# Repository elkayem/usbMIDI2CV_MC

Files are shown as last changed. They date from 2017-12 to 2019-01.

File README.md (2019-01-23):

# usbMIDI2CV_MC

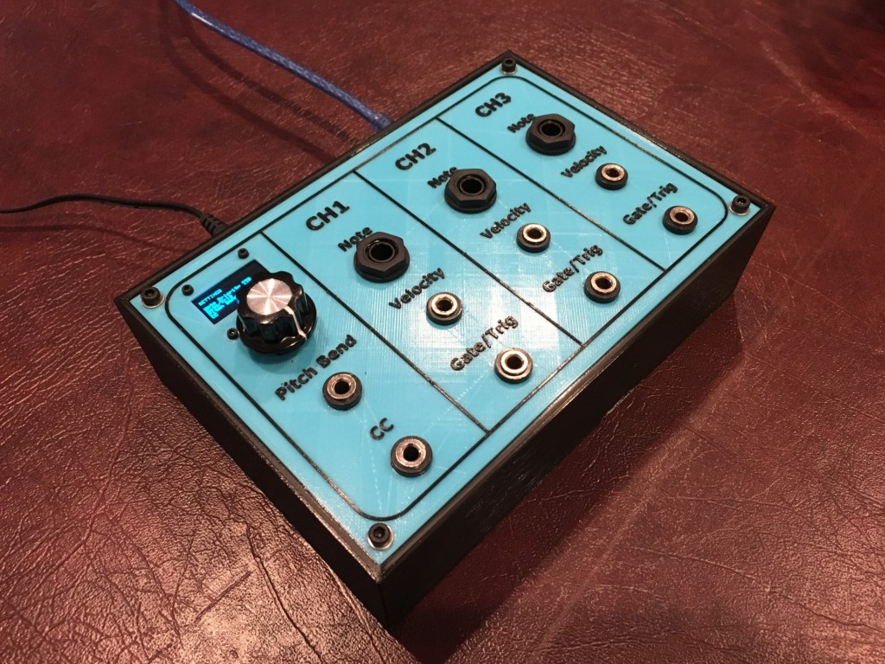
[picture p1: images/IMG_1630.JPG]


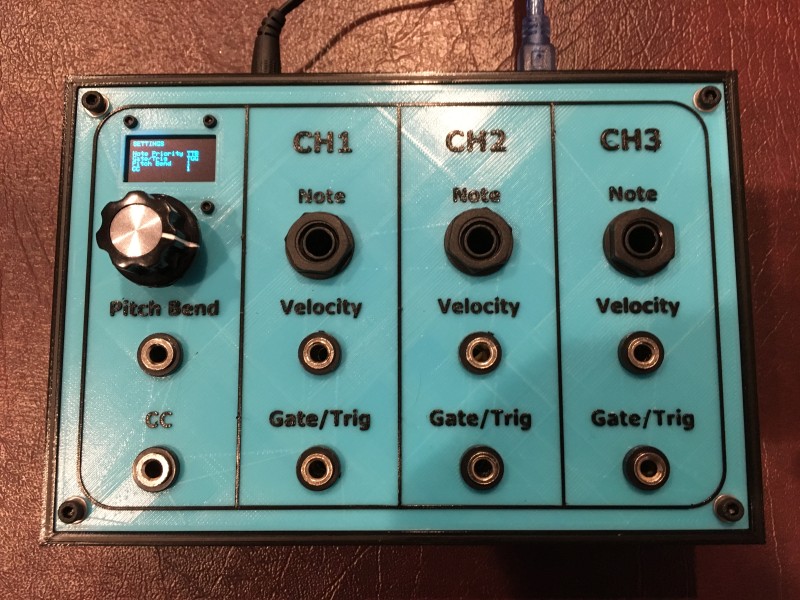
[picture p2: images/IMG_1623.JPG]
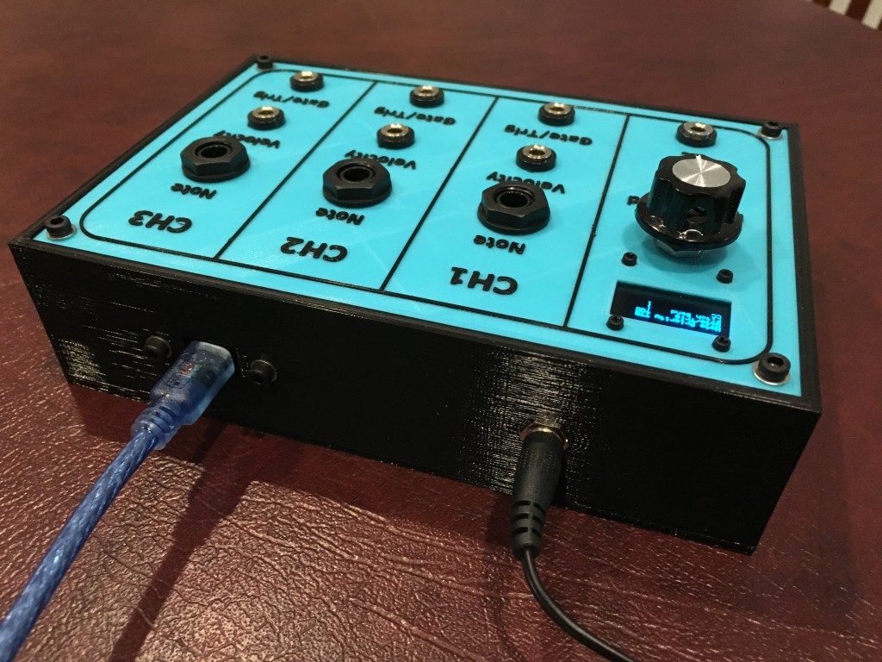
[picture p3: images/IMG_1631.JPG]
 

This repository contains the code and schematics for a three-channel USB-MIDI to CV converter.  STL files are also included for a 3D printed case.  This project has the following features:
* Three channel Note CV output (88 keys, 1V/octave, MIDI channels 1-3) using a 12-bit DAC
* Configurable note priority for each channel (Top Note, Bottom Note, or Last Note Priority)
* Note scale factor calibration configurable in software
* 5V Gate/Trigger outputs, where each channel can be independently configured to either output a gate (output high for entire length of time that note is on) or trigger (20 msec pulse each time a new note is initiated)
* Velocity CV output (0 to 4V) for each channel
* Pitch Bend CV output (0.5 +/- 0.5V), which can be configured for channel 1, 2, or 3
* Control Change CV output (0 to 4V), which can be configured for channel 1, 2, or 3
* OLED user interface, used for setting parameters and saving to EEPROM

This module is the perfect interface between your computer or iPad and an analog synthesizer.  It can independently drive up to three oscillators with 1V/octave CV inputs.  (Connection to an iPad requires the USB camera adapter but is well worth it given the wide variety of great MIDI sequencer apps.)  

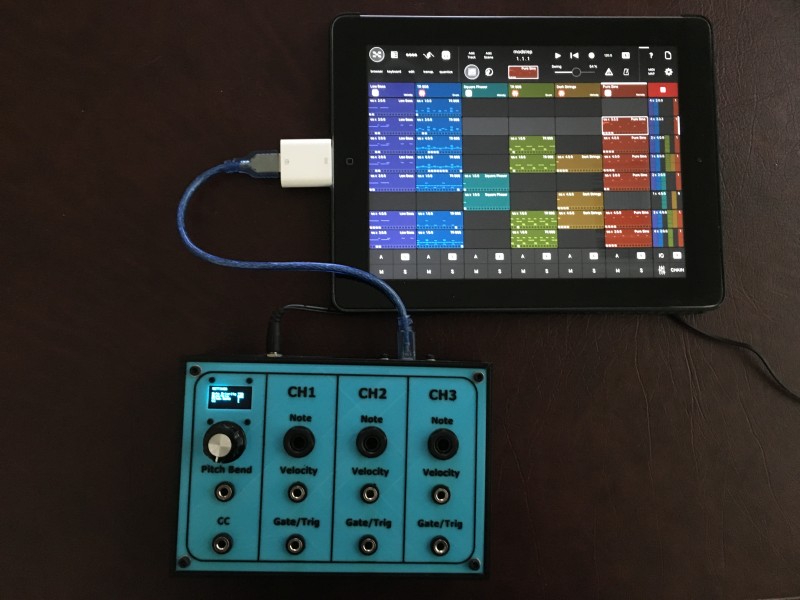
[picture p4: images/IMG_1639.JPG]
 

Note priority can be independengly set for each channel, with the following options:
* **Top Note (aka Highest Note):** When multiple notes are sounded simultaneously, the highest note being held will be sounded.  When the highest note is released, the next highest note will be played, and so on.
* **Bottom Note (aka Lowest Note):** Analagous to top note, except the lowest note being held will be sounded.  
* **Last Note:** The most recent note played will be sounded.  When that note is released, the next most recent note still being held will be sounded.  

The settings screen shows the current settings used.  Note priority is listed as sequence of three letters showing the setting for each of the three channels, where T = Top Note, B = Bottom Note, and L = Last Note.  Similarly, Gate/Trigger is listed as a sequence of three letters where G = Gate and T = Trigger.  Pitch Bend and CC settings show which MIDI channel will be used for the analog output.  Note scale factor can also be calibrated by +/-10%.  All of these settings can be set through the OLED interface using the encoder knob.

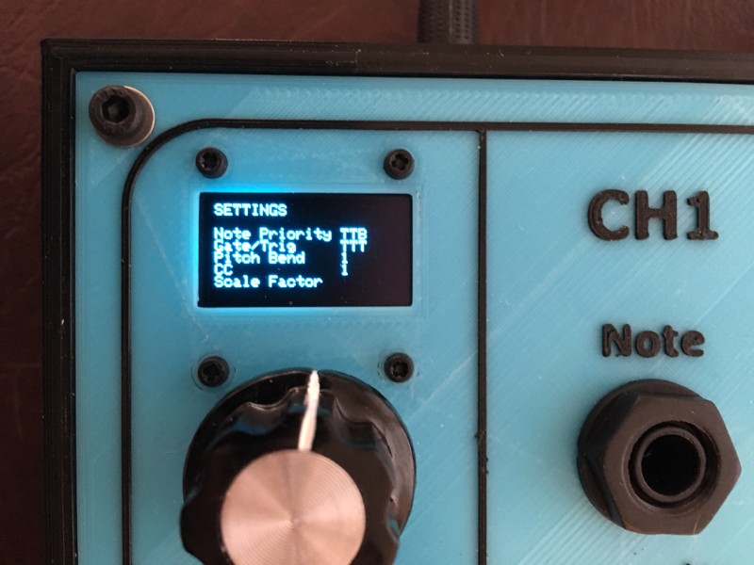
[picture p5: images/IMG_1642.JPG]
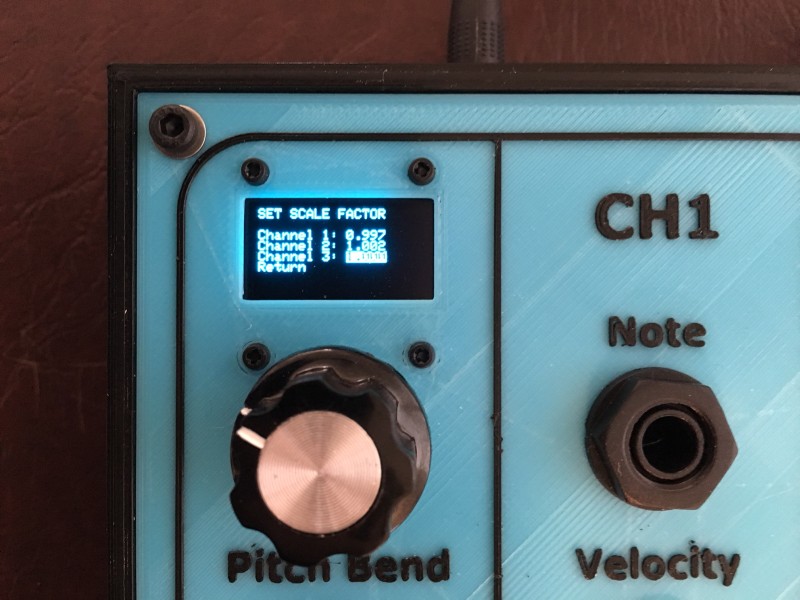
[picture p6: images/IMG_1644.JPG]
 

## Parts List
* Teensy 2.0
* LM7805 5V Voltage Regulator
* 128x64 OLED graphic display, with I2C interface 
* Pushbutton Rotary encoder with knob (should have 5 pins)
* 4x MCP4822 12-bit DACs (8 pin DIP)
* 2x LM324N Quad Op Amp (14 pin DIP)
* 7x 0.1 uF ceramic capacitors
* 0.33 uF capacitor
* 3x 3K resistors (1% metal film)
* 3x 4.7K resistors (1% metal film)
* 3x 10K resistors (1% metal film)
* 3x 2K resistors
* 4x 8 pin DIP IC sockets
* 2x 14 pin DIP IC sockets
* 2x 12-pin female headers
* 8x banana jacks
* 3x 1/4" mono phone jacks
* (Optional) 2-pin 5.08mm pitch screw terminal, for power input 
* Barrel power jack (e.g., 2.1 x 5.5 mm)
* 9 - 12V DC power supply with barrel connector (e.g., 2.1 x 5.5 mm)
* PCB (Gerber files included) or strip board
* 6x 10mm M3 bolts and nuts (4 for panel, 2 for USB port)
* 4x M2 bolts and nuts for mounting the OLED screen
* Panel mount USB 2.0 USB Mini B Female to USB Mini B Male, 1 ft cable (see picture below)

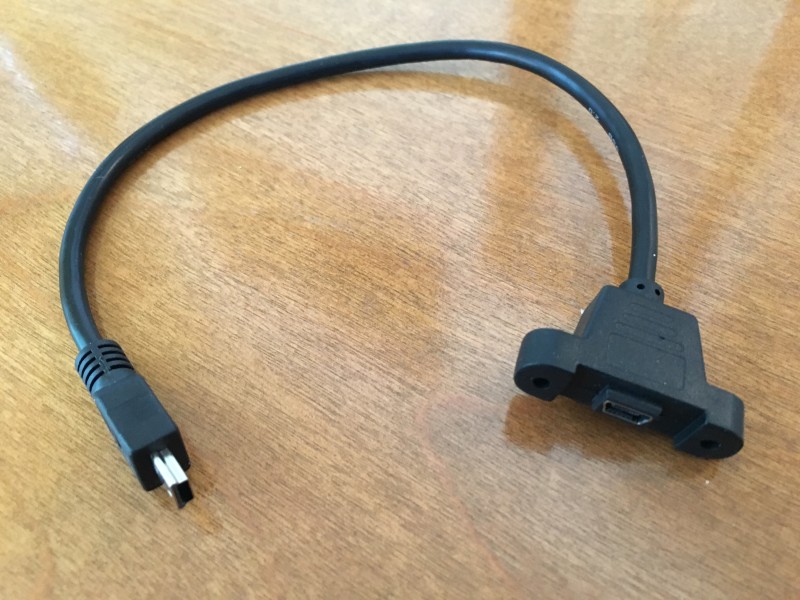
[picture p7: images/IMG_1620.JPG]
 

## Instructions
Electronic components can be soldered to a strip board or (more conveniently) to the PCB design I have included in this repository.  I recommend using IC sockets to mount the ICs and female headers to mount the Teensy.  The PCB can be manufactured by a PCB supplier.  The least expensive way to do this is to upload the gerber files (included as a .zip file) to one of several Chinese manufacturers such as SchenZhen2U, EasyEDA, or Seeed Studio.  pcbshopper.com allows a comparison between vendors.  Typical prices are $1-$3/board, with a minimum of 5 boards.  Recommended default settings are Layers: 2; PCB Thickness: 1.6mm; Surface Finish: HASL; Copper Weight: 1.  (Alternatively, contact me since I may still have a few extras I could send out for $5 + shipping.)

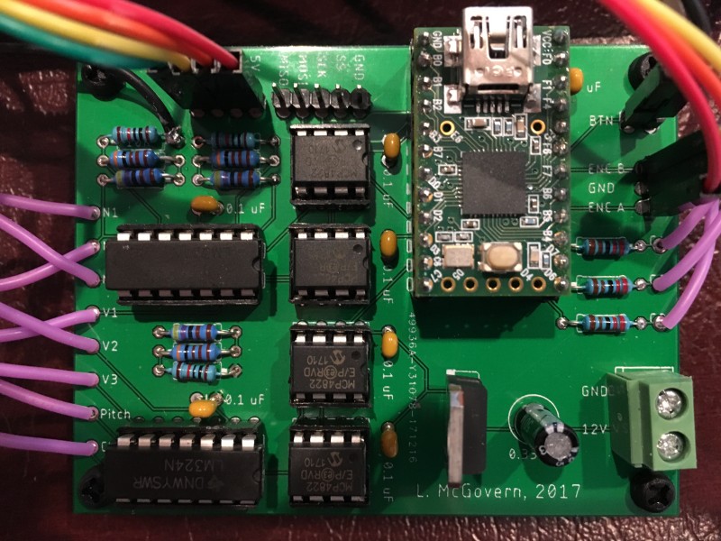
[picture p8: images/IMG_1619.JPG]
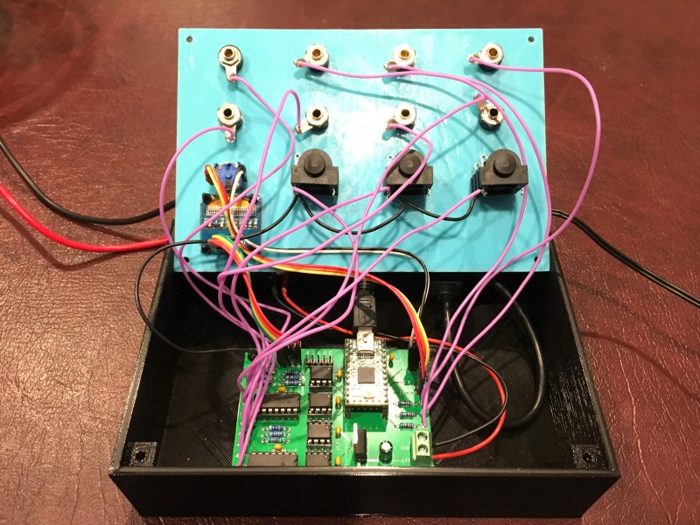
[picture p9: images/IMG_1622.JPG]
 

**Important!** Before connecting the Teensy 2.0 to an external power supply, the 5V pads must be cut on the bottom side of the board.  See https://www.pjrc.com/teensy/external_power.html for details.

The 3D printer STL files are located in the 3D Printer Files folder. I've also included the Sketchup file, in case modifications are needed.  (Download Sketchup Make, it's free!) The panel includes raised text, and so must be printed with two colors. Most slicers include a "pause at height" plugin, which will move the hot end out of the way and allow you to switch filaments. The panels are 3mm thick, and the letters are 0.45mm thick. I printed with 0.15mm layer thickness, allowing the letters to be printed in three layers. Add the command to pause after you finish printing the 3mm layer, so you can change the filament color. (One tip: If you find that your printer is disabling the stepper motors after pausing, you may need to insert M84 S0 at the start of the G-Code. I did.)  

The 3D printed panel must be printed with supports for the OLED screen mount. There is a recessed area on the back side of the panel that fits the screen mounting shape. I recommend picking up the screen by DIYMall, as the hole pattern was designed for that screen. Others may fit as well. Supports are not required for the case.

I have included 1/4" jacks for the CV note outputs to ensure that the analog synthesizer shares a common ground with the MIDI2CV component.  Ground is carried over the sleeve.  The sleeve pins on the phone jacks need to be tied together, and then tied to a ground location on the PCB.  I did not provide a dedicated ground location on the PCB for this connection, but any location on the PCB will work.  (e.g., directly to the power ground input).  I left the remainder of the outputs as banana jacks assuming at least one of the notes is connected.  If desired, the banana jacks can be replaced with phone jacks.  Be aware that the holes in the 3D printed case may need to be enlarged, and and the case may need to be made taller to accomodate the depth of the additional phone jacks. 

The rotary encoder should have three pins on one side and two on the other.  Connect the three pins to the 3 ENC headers on the board, and the two pins to the 2 BTN pins on the board.  These may be connected using jumper wires and male header pins, or soldered directly to the board.

The OLED attaches to the I2C output on the PCB (marked as 5V, GND, SCL, SDA).  Note the pin order!  This order matches a commonly available OLED from DIYMall, but other OLEDs exist with the power and ground swapped.  Swapping power and ground will destroy the OLED.

The firmware can be uploaded to the Teensy 2.0 using the Teensy loader.  See https://www.pjrc.com/teensy/first_use.html for details.  The hex file is included in this repository.  If modification of the source code is required, then the Arduino software and Teensyduino must also be installed (see https://www.pjrc.com/teensy/td_download.html).  Several libraries are used, which are included as part of the Teensyduino installer.  Be sure to configure the board as Teensy 2.0 (under Tools > Board), and USB Port as MIDI (under Tools > USB Type).

**Important Notes if recompiling firmware:**  
* You must be using Teensyduino 1.45 or later to recompile the software.  Earlier versions used a different internal numbering convention for MIDI message types.  The latest version can be downloaded from https://www.pjrc.com/teensy/td_download.html.  
* If the software isn't compiling, check your library version numbers.  I am currently using Adafruit SSD1306 v1.2.9 and Bounce2 v2.52.2.  The remaining libraries should come preinstalled with the Arduino and Teensyduino installers.

If using 1% metal film resistors, the MIDI2CV is likely to be in tune for the entire 7.25 octave (88 key) range.  The DAC output range is 4.096 V, which is amplified by 7.25/4.096 = 1.7700.  This is accomplished with the combination of 3K, 4.7K, and 10K resistors in the op-amp circuit.  (Note 3.01K is also common, and can be used.)  

If the MIDI2CV output scale factor isn't exactly 1V/octave, the scale factor can be adjusted by +/-10% using the user interface.  Mine was fairly close for all three channels, and required adjustment of only a few tenths of a percent.

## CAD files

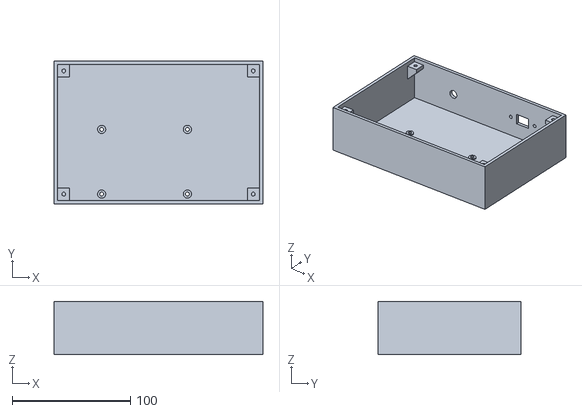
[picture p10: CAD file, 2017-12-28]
3D Printer Files/usbMIDI2CV_MC_case.stl
176.5 x 120.5 x 45.0

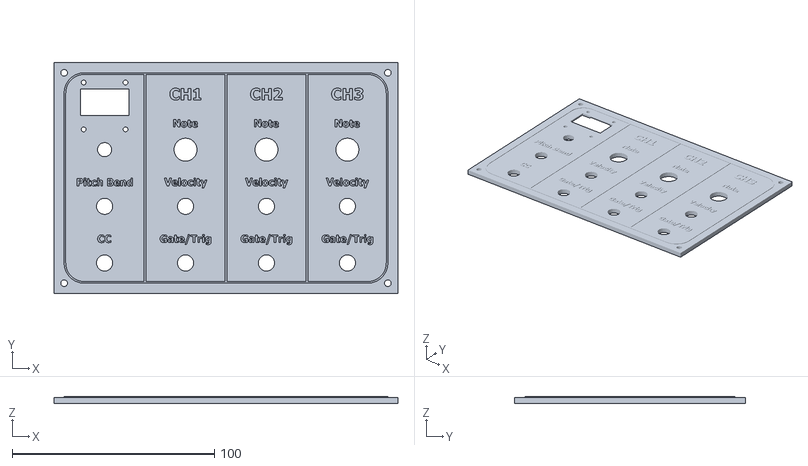
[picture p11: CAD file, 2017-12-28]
3D Printer Files/usbMIDI2CV_MC_panel.stl
170.0 x 114.0 x 3.45

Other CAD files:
3D Printer Files/usbMIDI2CV_MC.skp

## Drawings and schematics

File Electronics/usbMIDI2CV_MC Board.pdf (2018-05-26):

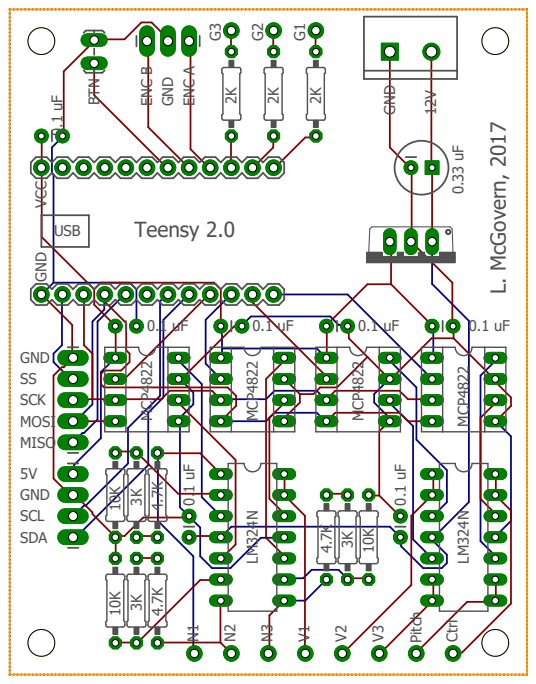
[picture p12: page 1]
MOSI MISO; SCK; GND; 5V GND SCL; SDA; L. McGovern, 2017

ENC B GND ENC A N1N2N3V1V2V3Ctrl G3G2G1 BTN GND 12V GND VCC USB Teensy 2.0 Pitch 2K2K2K 0.33 uF 10K 10K 10K 3K 3K 3K 4.7K 4.7K 4.7K LM324N LM324N MCP4822 MCP4822 MCP4822 MCP4822

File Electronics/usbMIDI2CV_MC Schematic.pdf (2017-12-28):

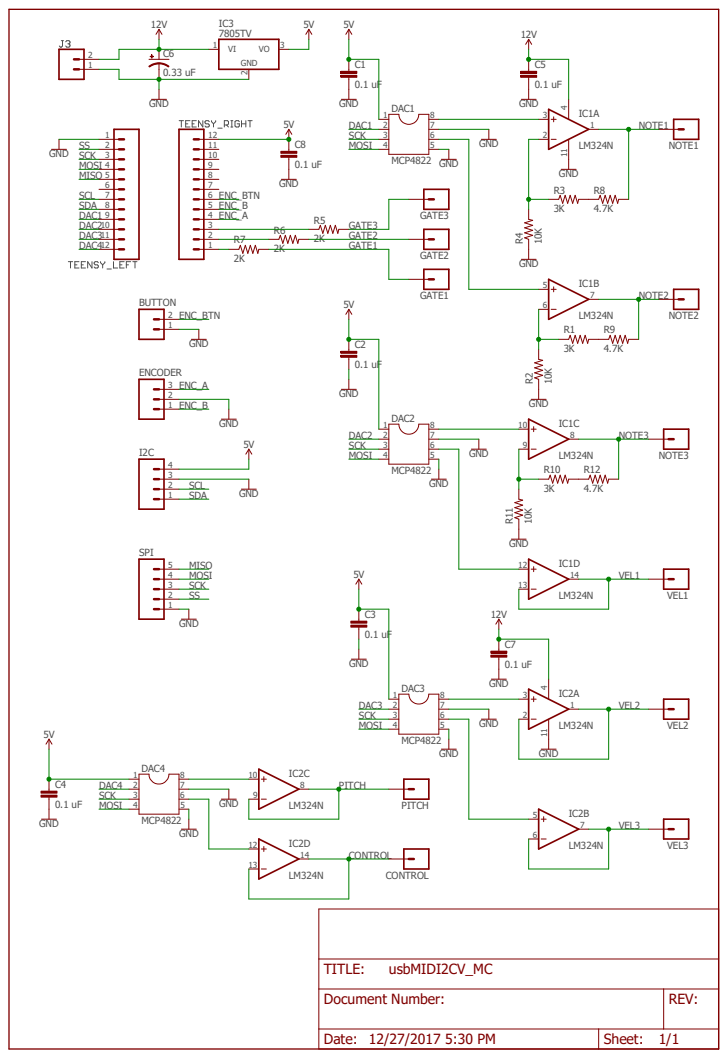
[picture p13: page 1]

Document Number: | REV:

Date: 12/27/2017 5:30 PM | Sheet: 1/1

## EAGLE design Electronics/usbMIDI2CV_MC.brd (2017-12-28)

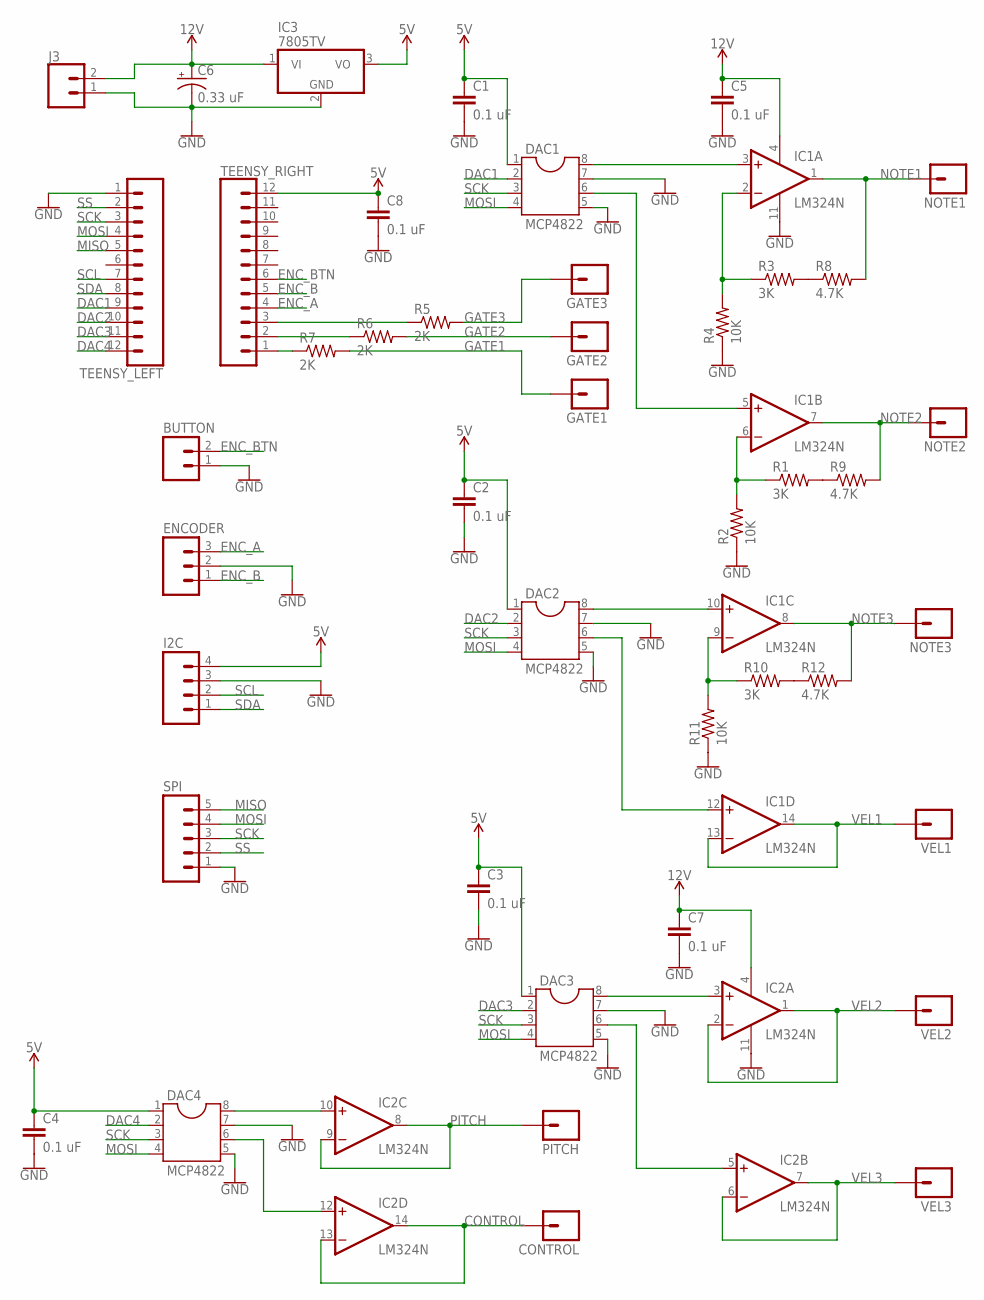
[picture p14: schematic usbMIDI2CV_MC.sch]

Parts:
BUTTON: M02LOCK_LONGPADS; 1X02_LOCK_LONGPADS
C1, C2, C3, C4, C5, C7, C8: 0.1 uF; CAP-PTH-SMALL
C6: 0.33 uF; CPOL-RADIAL-100UF-25V
CONTROL: M01PTH_NO_SILK_YES_STOP; 1X01_NO_SILK
DAC1, DAC2, DAC3, DAC4: MCP4822; SOCKET-08
ENCODER: M03LONGPADS; 1X03_LONGPADS
GATE1, GATE2, GATE3: M01PTH_NO_SILK_YES_STOP; 1X01_NO_SILK
I2C: M04LONGPADS; 1X04_LONGPADS
IC1, IC2: LM324N; DIL14
IC3: 7805TV; TO220V
J3: CONN_025MM; SCREWTERMINAL-5MM-2
NOTE1, NOTE2, NOTE3: M01PTH_NO_SILK_YES_STOP; 1X01_NO_SILK
PITCH: M01PTH_NO_SILK_YES_STOP; 1X01_NO_SILK
R1, R3, R10: 3K; 0207/10
R2, R4, R11: 10K; 0207/10
R5, R6, R7: 2K; 0207/10
R8, R9, R12: 4.7K; 0207/10
SPI: M05PTH_LONGPADS; 1X05_LONGPADS
TEENSY_LEFT: CONN_12; 1X12
TEENSY_RIGHT: CONN_12; 1X12
VEL1, VEL2, VEL3: M01PTH_NO_SILK_YES_STOP; 1X01_NO_SILK

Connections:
5V: C1.1, C2.1, C3.1, C4.1, C8.1, DAC1.1, DAC2.1, DAC3.1, DAC4.1, I2C.4, IC3.3 (VO), TEENSY_RIGHT.12
12V: C5.1, C6.1 (+), C7.1, IC1.4 (V+), IC2.4 (V+), IC3.1 (VI), J3.2
CONTROL: CONTROL.1, IC2.13 (-IN), IC2.14 (OUT)
DAC1: DAC1.2, TEENSY_LEFT.9
DAC2: DAC2.2, TEENSY_LEFT.10
DAC3: DAC3.2, TEENSY_LEFT.11
DAC4: DAC4.2, TEENSY_LEFT.12
ENC_A: ENCODER.3, TEENSY_RIGHT.4
ENC_B: ENCODER.1, TEENSY_RIGHT.5
ENC_BTN: BUTTON.2, TEENSY_RIGHT.6
GATE1: GATE1.1, R7.2
GATE2: GATE2.1, R6.2
GATE3: GATE3.1, R5.2
GND: BUTTON.1, C1.2, C2.2, C3.2, C4.2, C5.2, C6.2 (-), C7.2, C8.2, DAC1.5, DAC1.7, DAC2.5, DAC2.7, DAC3.5, DAC3.7, DAC4.5, DAC4.7, ENCODER.2, I2C.3, IC1.11 (V-), IC2.11 (V-), IC3.2 (GND), J3.1, R2.1, R4.1, R11.1, SPI.1, TEENSY_LEFT.1
MISO: SPI.5, TEENSY_LEFT.5
MOSI: DAC1.4, DAC2.4, DAC3.4, DAC4.4, SPI.4, TEENSY_LEFT.4
unnamed: IC1.6 (-IN), R1.1, R2.2
unnamed: R1.2, R9.1
unnamed: IC1.9 (-IN), R10.1, R11.2
unnamed: DAC1.8, IC1.3 (+IN)
unnamed: R3.2, R8.1
unnamed: IC1.2 (-IN), R3.1, R4.2
unnamed: DAC1.6, IC1.5 (+IN)
unnamed: DAC2.8, IC1.10 (+IN)
unnamed: DAC2.6, IC1.12 (+IN)
unnamed: R10.2, R12.1
unnamed: DAC3.8, IC2.3 (+IN)
unnamed: R5.1, TEENSY_RIGHT.3
unnamed: DAC3.6, IC2.5 (+IN)
unnamed: DAC4.6, IC2.12 (+IN)
unnamed: DAC4.8, IC2.10 (+IN)
unnamed: R6.1, TEENSY_RIGHT.2
unnamed: R7.1, TEENSY_RIGHT.1
NOTE1: IC1.1 (OUT), NOTE1.1, R8.2
NOTE2: IC1.7 (OUT), NOTE2.1, R9.2
NOTE3: IC1.8 (OUT), NOTE3.1, R12.2
PITCH: IC2.8 (OUT), IC2.9 (-IN), PITCH.1
SCK: DAC1.3, DAC2.3, DAC3.3, DAC4.3, SPI.3, TEENSY_LEFT.3
SCL: I2C.2, TEENSY_LEFT.7
SDA: I2C.1, TEENSY_LEFT.8
SS: SPI.2, TEENSY_LEFT.2
VEL1: IC1.13 (-IN), IC1.14 (OUT), VEL1.1
VEL2: IC2.1 (OUT), IC2.2 (-IN), VEL2.1
VEL3: IC2.6 (-IN), IC2.7 (OUT), VEL3.1

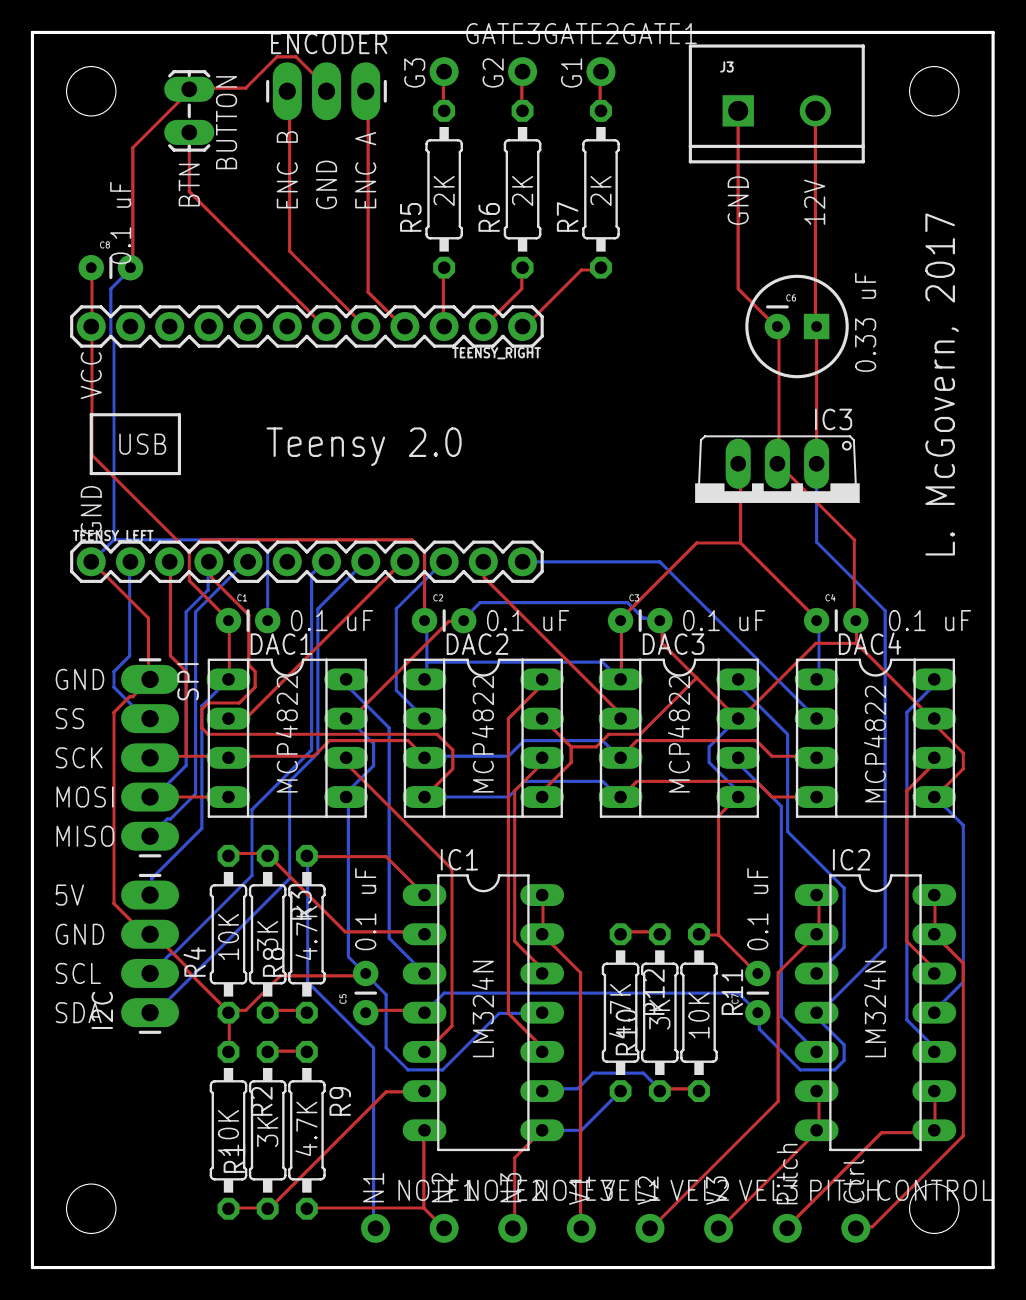
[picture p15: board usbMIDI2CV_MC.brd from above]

Board: 2 copper layers, 62.2 x 80.0 mm, 45 parts (0 on the bottom side), 44 nets.

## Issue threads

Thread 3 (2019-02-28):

Glide/Portamento Feature

Fisico, 2019-02-28:
Hi,
is it possible to implement "Glide/Portamento"?
It could be controlled with the encoder.

Fisico, 2019-09-09:
@elkayem
Any update on this feature request?
I really like the converter but Glide/Portamento is missing. Many commercial products are having this feature. But most of them are only single voice and 3 voices are very nice....

elkayem, 2020-01-10:
Hi Fisico, this sounds like a good feature. If someone were to make a good implementation of this, I would certainly merge it into the code. Closing this issue because it really isn't an issue.

Closed 2020-01-10.

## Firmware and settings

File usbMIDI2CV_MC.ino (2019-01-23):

/* 
 *    usbMIDI2CV_MC 
 *    Copyright (C) 2018  Larry McGovern
 *  
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
 *    This program is distributed in the hope that it will be useful,
 *    but WITHOUT ANY WARRANTY; without even the implied warranty of
 *    MERCHANTABILITY or FITNESS FOR A PARTICULAR PURPOSE.  See the
 *    GNU General Public License <http://www.gnu.org/licenses/> for more details.
 */
 
#include <SPI.h>
#include <Wire.h>
#include <Adafruit_SSD1306.h>
#include <EEPROM.h>
#include <Bounce2.h>

// OLED I2C is used on pins 5 and 6

#define DAC1      7
#define DAC2      8
#define DAC3      9
#define DAC4      10
#define GATE_CH0  11
#define GATE_CH1  12
#define GATE_CH2  13

#define ENC_A   14
#define ENC_B   15
#define ENC_BTN 16


#define GATE(CH) (CH==0 ? GATE_CH0 : (CH==1 ? GATE_CH1 : GATE_CH2))

// Note CH0: DAC1, A
// Note CH1: DAC1, B
// Note CH2: DAC2, A
#define NOTE_DAC(CH) (CH==2 ? DAC2 : DAC1)
#define NOTE_AB(CH)  (CH==1 ? 1 : 0)

// Vel CH0: DAC2, B
// Vel CH1: DAC3, A
// Vel CH2: DAC3, B
#define VEL_DAC(CH) (CH==0 ? DAC2 : DAC3)
#define VEL_AB(CH)  (CH==1 ? 0 : 1)

#define PITCH_DAC DAC4
#define PITCH_AB  0
#define CC_DAC    DAC4
#define CC_AB     1

#define OLED_RESET 17
#define SCREEN_WIDTH 128 // OLED display width, in pixels
#define SCREEN_HEIGHT 64 // OLED display height, in pixels
Adafruit_SSD1306 display(SCREEN_WIDTH, SCREEN_HEIGHT, &Wire, OLED_RESET);

int encoderPos, encoderPosPrev;
Bounce encButton = Bounce(); 

enum Menu {
  SETTINGS,
  NOTE_PRIORITY,
  NOTE_PRIORITY_SET_CH,
  GATE_TRIG,
  GATE_TRIG_SET_CH,
  PITCH_BEND_SET_CH,
  CC_SET_CH,
  SCALE_FACTOR,
  SCALE_FACTOR_SET_CH
} menu;

char notePriority[] = "TTT";
char gateTrig[] = "GGG";
float sfAdj[3];

uint8_t pitchBendChan;
uint8_t ccChan;

// EEPROM Addresses
#define ADDR_NOTE_PRIORITY 0
#define ADDR_GATE_TRIG     3
#define ADDR_PITCH_BEND    6
#define ADDR_CC            7
#define ADDR_SF_ADJUST     8

bool highlightEnabled = false;  // Flag indicating whether highighting should be enabled on menu
#define HIGHLIGHT_TIMEOUT 20000  // Highlight disappears after 20 seconds.  Timer resets whenever encoder turned or button pushed
unsigned long int highlightTimer = 0;  

void setup()
{
 pinMode(GATE_CH0, OUTPUT);
 pinMode(GATE_CH1, OUTPUT);
 pinMode(GATE_CH2, OUTPUT);
 pinMode(DAC1, OUTPUT);
 pinMode(DAC2, OUTPUT);
 pinMode(DAC3, OUTPUT);
 pinMode(DAC4, OUTPUT);
 pinMode(ENC_A, INPUT_PULLUP);
 pinMode(ENC_B, INPUT_PULLUP);
 pinMode(ENC_BTN,INPUT_PULLUP);
  
 digitalWrite(GATE_CH0,LOW);
 digitalWrite(GATE_CH1,LOW);
 digitalWrite(GATE_CH2,LOW);
 digitalWrite(DAC1,HIGH);
 digitalWrite(DAC2,HIGH);
 digitalWrite(DAC3,HIGH);
 digitalWrite(DAC4,HIGH);

 SPI.begin();

 display.begin(SSD1306_SWITCHCAPVCC, 0x3C); // OLED I2C Address, may need to change for different device,
                                            // Check with I2C_Scanner

 //Wire.setClock(100000L);  // Uncomment to slow down I2C speed

 // Read Settings from EEPROM
 for (int i=0; i<3; i++) {
   notePriority[i] = (char)EEPROM.read(ADDR_NOTE_PRIORITY+i);
   gateTrig[i] = (char)EEPROM.read(ADDR_GATE_TRIG+i);
   EEPROM.get(ADDR_SF_ADJUST+i*sizeof(float), sfAdj[i]);

  // Set defaults if EEPROM not initialized
  if (notePriority[i] != 'T' && notePriority[i] != 'B' && notePriority[i] != 'L') notePriority[i] = 'T';
  if (gateTrig[i] != 'G' && gateTrig[i] != 'T') gateTrig[i] = 'G';
  if ((sfAdj[i] < 0.9f) || (sfAdj[i] > 1.1f) || isnan(sfAdj[i])) sfAdj[i] = 1.0f; 
 }
  
 pitchBendChan = EEPROM.read(ADDR_PITCH_BEND);
 ccChan = EEPROM.read(ADDR_CC);

// Set defaults if EEPROM not initialized
 if (pitchBendChan > 2) pitchBendChan = 0;
 if (ccChan > 2) ccChan = 0;

 encButton.attach(ENC_BTN);
 encButton.interval(5);  // interval in ms

 menu = SETTINGS;
 updateSelection();
}


unsigned long trigTimer[3] = {0};
bool notes[3][88] = {0}, initial_loop = 1; 
int8_t noteOrder[3][10] = {0}, orderIndx[3] = {0};

void loop()
{
  int8_t noteMsg, velocity, channel, d2, i;

  updateEncoderPos();  
  encButton.update();

 if (encButton.fell()) {  
   if (initial_loop == 1) {
     initial_loop = 0;  // Ignore first push after power-up
    }
   else {
     updateMenu();
    }
   }

  // Check if highlighting timer expired, and remove highlighting if so
  if (highlightEnabled && ((millis() - highlightTimer) > HIGHLIGHT_TIMEOUT)) {  
    highlightEnabled = false;
    menu = SETTINGS;    // Return to top level menu
    updateSelection();  // Refresh screen without selection highlight
  }
  
  for (i=0;i<3;i++) {
    if ((trigTimer[i] > 0) && (millis() - trigTimer[i] > 20) && gateTrig[i] == 'T') { 
      digitalWrite(GATE(i),LOW); // Set trigger low after 20 msec 
      trigTimer[i] = 0;  
    }
  }
  
  if (usbMIDI.read()) {                    
    byte type = usbMIDI.getType();
    switch (type) {
        
      case usbMIDI.NoteOff:
      case usbMIDI.NoteOn:
        noteMsg = usbMIDI.getData1() - 21; // A0 = 21, Top Note = 108
        channel = usbMIDI.getChannel()-1;

        if (channel > 2) return;  // Only channel 0,1,2 supported
        if ((noteMsg < 0) || (noteMsg > 87)) break;  // Only 88 notes of keyboard are supported

        if (type == usbMIDI.NoteOn) velocity = usbMIDI.getData2();
        else velocity  = 0;  

        if (velocity == 0)  {
          notes[channel][noteMsg] = false;
        }
        else {
          notes[channel][noteMsg] = true;
          commandVel(velocity, channel); 
        }

        if (notePriority[channel] == 'T') // Top note priority
          commandTopNote(channel);
        else if (notePriority[channel] == 'B') // Bottom note priority
          commandBottomNote(channel);
        else { // Last note priority  
          if (notes[channel][noteMsg]) {  // If note is on and using last note priority, add to ordered list
            orderIndx[channel] = (orderIndx[channel]+1) % 10;
            noteOrder[channel][orderIndx[channel]] = noteMsg;                 
          }
          commandLastNote(channel);
        }
            
        break;
        
      case usbMIDI.PitchBend:
        if (usbMIDI.getChannel() == pitchBendChan) {
          // Pitch bend output from 0 to 1023 mV.  Left shift d2 by 4 to scale from 0 to 2047.
          // With DAC gain = 1X, this will yield a range from 0 to 1023 mV.  Additional amplification
          // after DAC will rescale to -1 to +1V.
          d2 = usbMIDI.getData2(); // d2 from 0 to 127, mid point = 64
          setVoltage(PITCH_DAC, PITCH_AB, 0, d2<<4);  // DAC2, channel 0, gain = 1X
        }
        break;

      case usbMIDI.ControlChange: 
        if (usbMIDI.getChannel() == ccChan) {
          d2 = usbMIDI.getData2(); 
          // CC range from 0 to 4095 mV  Left shift d2 by 5 to scale from 0 to 4095, 
          // and choose gain = 2X
          setVoltage(CC_DAC, CC_AB, 1, d2<<5);  // DAC2, channel 1, gain = 2X
        }
        break;

    }
  }
}


void commandTopNote(int channel)
{
  int topNote = 0;
  bool noteActive = false;
 
  for (int i=0; i<88; i++)
  {
    if (notes[channel][i]) {
      topNote = i;
      noteActive = true;
    }
  }

  if (noteActive) 
    commandNote(topNote, channel);
  else // All notes are off, turn off gate
    digitalWrite(GATE(channel),LOW);
}

void commandBottomNote(int channel)
{
  int bottomNote = 0;
  bool noteActive = false;
 
  for (int i=87; i>=0; i--)
  {
    if (notes[channel][i]) {
      bottomNote = i;
      noteActive = true;
    }
  }

  if (noteActive) 
    commandNote(bottomNote, channel);
  else // All notes are off, turn off gate
    digitalWrite(GATE(channel),LOW);
}

void commandLastNote(int channel)
{
  int8_t noteIndx;
  
  for (int i=0; i<10; i++) {
    noteIndx = noteOrder[channel][ mod(orderIndx[channel]-i, 10) ];
    if (notes[channel][noteIndx]) {
      commandNote(noteIndx,channel);
      return;
    }
  }
  digitalWrite(GATE(channel),LOW);  // All notes are off
}

// Rescale 88 notes to 4096 mV:
//    noteMsg = 0 -> 0 mV 
//    noteMsg = 87 -> 4096 mV
// DAC output will be (4095/87) = 47.069 mV per note, and 564.9655 mV per octave
// Note that DAC output will need to be amplified by 1.77X for the standard 1V/octave 
#define NOTE_SF 47.069f 

void commandNote(int noteMsg, int channel) {
  digitalWrite(GATE(channel),HIGH);
  trigTimer[channel] = millis();
  
  unsigned int mV = (unsigned int) ((float) noteMsg * NOTE_SF * sfAdj[channel] + 0.5);   
  setVoltage(NOTE_DAC(channel), NOTE_AB(channel), 1, mV);  
}


// commandVel -- Command velocity DAC
void commandVel(int velocity, int8_t channel) {
  // velocity range from 0 to 4095 mV  Left shift d2 by 5 to scale from 0 to 4095, 
  // and choose gain = 2X
  setVoltage(VEL_DAC(channel), VEL_AB(channel), 1, velocity<<5);  
}

// setVoltage -- Set DAC voltage output
// dacpin: chip select pin for DAC.  Note and velocity on DAC1, pitch bend and CC on DAC2
// channel: 0 (A) or 1 (B).  
// gain: 0 = 1X, 1 = 2X.  
// mV: integer 0 to 4095.  If gain is 1X, mV is in units of half mV (i.e., 0 to 2048 mV).
// If gain is 2X, mV is in units of mV

void setVoltage(int dacpin, bool channel, bool gain, unsigned int mV)
{
  int command = channel ? 0x9000 : 0x1000;

  command |= gain ? 0x0000 : 0x2000;
  command |= (mV & 0x0FFF);
  
  SPI.beginTransaction(SPISettings(8000000, MSBFIRST, SPI_MODE0));
  digitalWrite(dacpin,LOW);
  SPI.transfer(command>>8);
  SPI.transfer(command&0xFF);
  digitalWrite(dacpin,HIGH);
  SPI.endTransaction();
}


void updateEncoderPos() {
    static int encoderA, encoderB, encoderA_prev;   

    encoderA = digitalRead(ENC_A); 
    encoderB = digitalRead(ENC_B);
      
    if((!encoderA) && (encoderA_prev)){ // A has gone from high to low 
      if (highlightEnabled) { // Update encoder position
        encoderPosPrev = encoderPos;
        encoderB ? encoderPos++ : encoderPos--;  
      }
      else { 
        highlightEnabled = true;
        encoderPos = 0;  // Reset encoder position if highlight timed out
        encoderPosPrev = 0;
      }
      highlightTimer = millis(); 
      updateSelection();
    }
    encoderA_prev = encoderA;     
}

int setCh;

void updateMenu() {  // Called whenever button is pushed

  if (highlightEnabled) { // Highlight is active, choose selection
    switch (menu) {
      case SETTINGS:
        switch (mod(encoderPos,5)) {
          case 0: 
            menu = NOTE_PRIORITY;
            break;
          case 1: 
            menu = GATE_TRIG;
            break;
          case 2: 
            menu = PITCH_BEND_SET_CH;
            break;
          case 3: 
            menu = CC_SET_CH;
            break;
          case 4: 
            menu = SCALE_FACTOR;
            break;
        }
        break;
        
      case NOTE_PRIORITY:
        setCh = mod(encoderPos,4);
        switch (setCh) {
          case 0: 
          case 1: 
          case 2: 
            menu = NOTE_PRIORITY_SET_CH;
            break;
          case 3: 
            menu = SETTINGS;
            break;
        }
        break;
        
      case NOTE_PRIORITY_SET_CH:  // Save note priority setting to EEPROM
        menu = NOTE_PRIORITY;
        EEPROM.write(ADDR_NOTE_PRIORITY+setCh, notePriority[setCh]);
        break;
        
      case GATE_TRIG:
        setCh = mod(encoderPos,4);
        switch (setCh) {
          case 0: 
          case 1: 
          case 2: 
            menu = GATE_TRIG_SET_CH;
            break;
          case 3: 
            menu = SETTINGS;
            break;
        }
        break;
  
      case GATE_TRIG_SET_CH:  // Save gate/trigger setting to EEPROM
        menu = GATE_TRIG;
        EEPROM.write(ADDR_GATE_TRIG+setCh, gateTrig[setCh]);
        break;
  
      case PITCH_BEND_SET_CH:  // Save pitch bend setting to EEPROM
        menu = SETTINGS;
        EEPROM.write(ADDR_PITCH_BEND, pitchBendChan);
        break;
        
      case CC_SET_CH:  // Save pitch bend setting to EEPROM
        menu = SETTINGS;
        EEPROM.write(ADDR_CC, ccChan);
        break;

      case SCALE_FACTOR:
        setCh = mod(encoderPos,4);
        switch (setCh) {
          case 0: 
          case 1: 
          case 2: 
            menu = SCALE_FACTOR_SET_CH;
            break;
          case 3: 
            menu = SETTINGS;
            break;
        }
        break;
        
      case SCALE_FACTOR_SET_CH: // Save scale factor to EEPROM
        menu = SCALE_FACTOR;
        EEPROM.put(ADDR_SF_ADJUST+setCh*sizeof(float), sfAdj[setCh]);
        break;      
    }
  }
  else { // Highlight wasn't visible, reinitialize highlight timer
    highlightTimer = millis();
    highlightEnabled = true;
  }
  encoderPos = 0;  // Reset encoder position
  encoderPosPrev = 0;
  updateSelection(); // Refresh screen
}

void updateSelection() { // Called whenever encoder is turned
  display.clearDisplay();
  switch (menu) {
    case PITCH_BEND_SET_CH:
      pitchBendChan = mod(encoderPos, 3);
      // No break statement, continue through next case
    case CC_SET_CH:
      if (menu == CC_SET_CH) ccChan = mod(encoderPos, 3);
      // No break statement, continue through next case
    case SETTINGS:
      display.setCursor(0,0); 
      display.setTextColor(WHITE,BLACK);
      display.print(F("SETTINGS"));
      display.setCursor(0,16);
      
      if (menu == SETTINGS) setHighlight(0,5);
      display.print(F("Note Priority "));
      display.println(notePriority);
      
      if (menu == SETTINGS) setHighlight(1,5);
      display.print(F("Gate/Trig     "));
      display.println(gateTrig);
      
      if (menu == SETTINGS) setHighlight(2,5);
      display.print(F("Pitch Bend    "));
      if (menu == PITCH_BEND_SET_CH) display.setTextColor(BLACK,WHITE);
      display.print(pitchBendChan+1);
      display.println(F("  "));
      
      if (menu == SETTINGS) setHighlight(3,5);
      else display.setTextColor(WHITE,BLACK);
      display.print(F("CC            "));
      if (menu == CC_SET_CH) display.setTextColor(BLACK,WHITE);
      display.print(ccChan+1);
      display.println(F("  "));

      if (menu == SETTINGS) setHighlight(4,5);
      else display.setTextColor(WHITE,BLACK);
      display.println(F("Scale Factor     "));
      
      break;
      
    case NOTE_PRIORITY_SET_CH:
      switch (mod(encoderPos, 3)) {
        case 0:
          notePriority[setCh] = 'T';  // Top note
          break;
        case 1:
          notePriority[setCh] = 'B';  // Bottom note
          break;
        case 2: 
          notePriority[setCh] = 'L';  // Last note
          break;
      }
      // No break statement, continue through next case
    case NOTE_PRIORITY:
    
      display.setCursor(0,0); 
      display.setTextColor(WHITE,BLACK);
      display.print(F("SET NOTE PRIORITY"));
      display.setCursor(0,16);
      
      if (menu == NOTE_PRIORITY) setHighlight(0,4);
      display.print(F("Channel 1: "));
      if ((menu == NOTE_PRIORITY_SET_CH) && setCh == 0) display.setTextColor(BLACK,WHITE);
      display.println(notePriority[0]);
      
      if (menu == NOTE_PRIORITY) setHighlight(1,4);
      else display.setTextColor(WHITE,BLACK);
      display.print(F("Channel 2: "));
      if ((menu == NOTE_PRIORITY_SET_CH) && setCh == 1) display.setTextColor(BLACK,WHITE);
      display.println(notePriority[1]);
      
      if (menu == NOTE_PRIORITY) setHighlight(2,4);
      else display.setTextColor(WHITE,BLACK);
      display.print(F("Channel 3: ")); 
      if ((menu == NOTE_PRIORITY_SET_CH) && setCh == 2) display.setTextColor(BLACK,WHITE);
      display.println(notePriority[2]); 
      
      if (menu == NOTE_PRIORITY) setHighlight(3,4);
      else display.setTextColor(WHITE,BLACK);
      display.println(F("Return           "));       
      break;  
      
    case GATE_TRIG_SET_CH:
      switch (mod(encoderPos, 2)) {
        case 0:
          gateTrig[setCh] = 'G';  // Gate
          break;
        case 1:
          gateTrig[setCh] = 'T';  // Trigger
          break;
      }
      // No break statement, continue through next case
    case GATE_TRIG:
      display.setCursor(0,0); 
      display.setTextColor(WHITE,BLACK);
      display.print(F("SET GATE/TRIGGER"));
      display.setCursor(0,16);
      
      if (menu == GATE_TRIG) setHighlight(0,4);
      display.print(F("Channel 1: "));
      if ((menu == GATE_TRIG_SET_CH) && setCh == 0) display.setTextColor(BLACK,WHITE);
      display.println(gateTrig[0]);
      
      if (menu == GATE_TRIG) setHighlight(1,4);
      else display.setTextColor(WHITE,BLACK);
      display.print(F("Channel 2: "));
      if ((menu == GATE_TRIG_SET_CH) && setCh == 1) display.setTextColor(BLACK,WHITE);
      display.println(gateTrig[1]);
            
      if (menu == GATE_TRIG) setHighlight(2,4);
      else display.setTextColor(WHITE,BLACK);
      display.print(F("Channel 3: "));  
      if ((menu == GATE_TRIG_SET_CH) && setCh == 2) display.setTextColor(BLACK,WHITE);
      display.println(gateTrig[2]);
            
      if (menu == GATE_TRIG) setHighlight(3,4);
      else display.setTextColor(WHITE,BLACK);
      display.print(F("Return      "));  
      break;
      
    case SCALE_FACTOR_SET_CH:
        if ((encoderPos > encoderPosPrev) && (sfAdj[setCh] < 1.1))
            sfAdj[setCh] += 0.001f;
        else if ((encoderPos < encoderPosPrev) && (sfAdj[setCh] > 0.9))
            sfAdj[setCh] -= 0.001f;           
      // No break statement, continue through next case
    case SCALE_FACTOR:
      display.setCursor(0,0); 
      display.setTextColor(WHITE,BLACK);
      display.print(F("SET SCALE FACTOR"));   
      display.setCursor(0,16);
      
      if (menu == SCALE_FACTOR) setHighlight(0,4);
      display.print(F("Channel 1: "));
      if ((menu == SCALE_FACTOR_SET_CH) && setCh == 0) display.setTextColor(BLACK,WHITE);
      display.println(sfAdj[0],3);
      
      if (menu == SCALE_FACTOR) setHighlight(1,4);
      else display.setTextColor(WHITE,BLACK);
      display.print(F("Channel 2: "));
      if ((menu == SCALE_FACTOR_SET_CH) && setCh == 1) display.setTextColor(BLACK,WHITE);
      display.println(sfAdj[1],3);
            
      if (menu == SCALE_FACTOR) setHighlight(2,4);
      else display.setTextColor(WHITE,BLACK);
      display.print(F("Channel 3: "));  
      if ((menu == SCALE_FACTOR_SET_CH) && setCh == 2) display.setTextColor(BLACK,WHITE);
      display.println(sfAdj[2],3);
            
      if (menu == SCALE_FACTOR) setHighlight(3,4);
      else display.setTextColor(WHITE,BLACK);
      display.print(F("Return      "));  
       
  }
  display.display(); 
}

void setHighlight(int menuItem, int numMenuItems) {
  if ((mod(encoderPos, numMenuItems) == menuItem) &&  highlightEnabled ) {
    display.setTextColor(BLACK,WHITE);
  }
  else {
    display.setTextColor(WHITE,BLACK);
  }
}

int mod(int a, int b)
{
    int r = a % b;
    return r < 0 ? r + b : r;
}

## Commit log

2017-12-28 Initial check-in
    [usbMIDI2CV_MC.brd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]
2018-01-06 Add note scale factor calibration support.
2018-05-26 Add board pdf
2018-06-30 Update for compatibility with Teensyduino 1.41 and later.

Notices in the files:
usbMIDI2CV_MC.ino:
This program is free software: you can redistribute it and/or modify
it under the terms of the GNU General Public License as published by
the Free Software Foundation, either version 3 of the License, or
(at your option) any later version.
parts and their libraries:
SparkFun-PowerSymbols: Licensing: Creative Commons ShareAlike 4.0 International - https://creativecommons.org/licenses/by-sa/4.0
